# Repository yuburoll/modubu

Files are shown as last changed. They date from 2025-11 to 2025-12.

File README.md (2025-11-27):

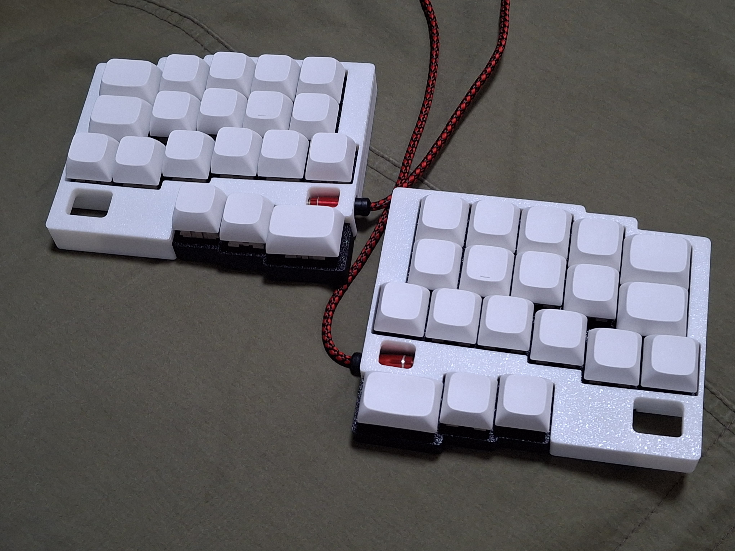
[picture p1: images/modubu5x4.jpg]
modubuImage


# modubu

[한국어 설명은 이곳에서 보실 수 있습니다](README_ko.md)

semi-staggered(half row staggered, half column staggered) 38 key split keyboard under 100x100mm PCB

The name "modubu" is tofu square in Korean.

Started idea on my old sketch and [KeeNoard](https://github.com/yuburoll/KeeNoard), finished and polished the idea thanks to the great [DYA Dash](https://cormoran.github.io/dya-dash-keyboard/).

(Really surprisingly, I made this similar layout when I don't know about DYA Dash.)

credit for 우주신제품(wujusinjepum), the anonymous who named this keyboard.

## Preparation

- 2x rp2040 zero (boards formly created by waveshare) (Approx. 4-8$)

- 2x modubu PCB Boards (5 boards are 2$ on JLC w/o shipping cost)

- 1x printed case sets, 6 parts total (Approx. 12$ if you buy printed one on JLC)

- 38x diodes (Approx. 1$)

- 22x M2x6 screws, flathead (Approx. 1$)

- 2x PJ320A 1/8(3.5mm) TRRS connector (Approx. 1$)

- 1x 1/8(3.5mm) TRRS cable (Approx. 2$, may TRS cable can take the place.)

- 38x MX Hotswap Sockets (Approx. 4$) (or, use soldering version)

- 38x MX Keyswitches & Keycaps (Maybe this cost varies too much. 10$ on average)

Approx. 37-41$(w/o shipping cost) needed to build one.

## Default Keymap

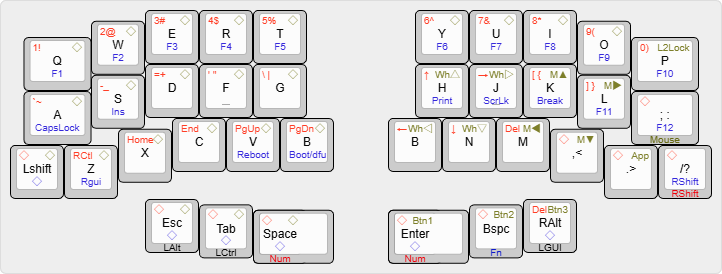
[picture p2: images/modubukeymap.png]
keymapImage


Holding the key triggers front legend.

There is three layers - Num, Mouse, Fn - which can be noticed by the color legends. ◇ Means Transparent; which uses base keymap.

## Build Guides

work in progress. sorry!

You can see the images in the folder, which uploaded for build guides. Especially you may see how to solder the controller board, because this uses surface mounting by castelated pins.

This uses [qmk](https://qmk.fm/) to build the firmware. Copy "modubu" folder which is in "firmware/qmk" directory to "qmk_firmware\keyboards" folder, and build it via qmk msys.

Or, simply flash uf2 in "uf2Examples" folder by changing rp2040 zero in dfu mode, which can be executed by holding boot button while plugging in usb c. Vial versions are also prepared.

## Notes

(from my reddit reply) 

I made this keyboard for very local and ethnic layouts - Especially Koreans.

Koreans have lots of vowels, so we use left hand for consonants and right hand for vowels. The tragedy starts from here: B position is vowel(ㅠ, yu) in Korean keyboard, so very lots of Korean typers press B in right hand, still they use B in left hand when they typing English words.

Many Korean split ergo keyboard users literally suffers with B position problem; and this is one of most stiff learning curve of them. Some exchanges semicolon to B key, some slides the bottom row or have double B (zxcvbnm,./ => /zxcvbnm,. or zxcvbbnm,.) and some just get used to it.

And after the B, Koreans type many word like CamelCaseVariables (eg. past sentence "있었습니다(it-sut-SOUP-nee-da)" types like "dlTdjTtmqslek") - which make home row mods very cumbersome. We may have seperated shift key for this.

So that's why I made row stagger split design with additional keys: But I was surprised that I'm not the first one with this idea and layout.

## Licenses

all codes follow MIT license.

all designs and the hardware board follow CC BY-SA 4.0 license.

If you want to make a commercial product, it would be appreciated if you sponsor some bucks for me.

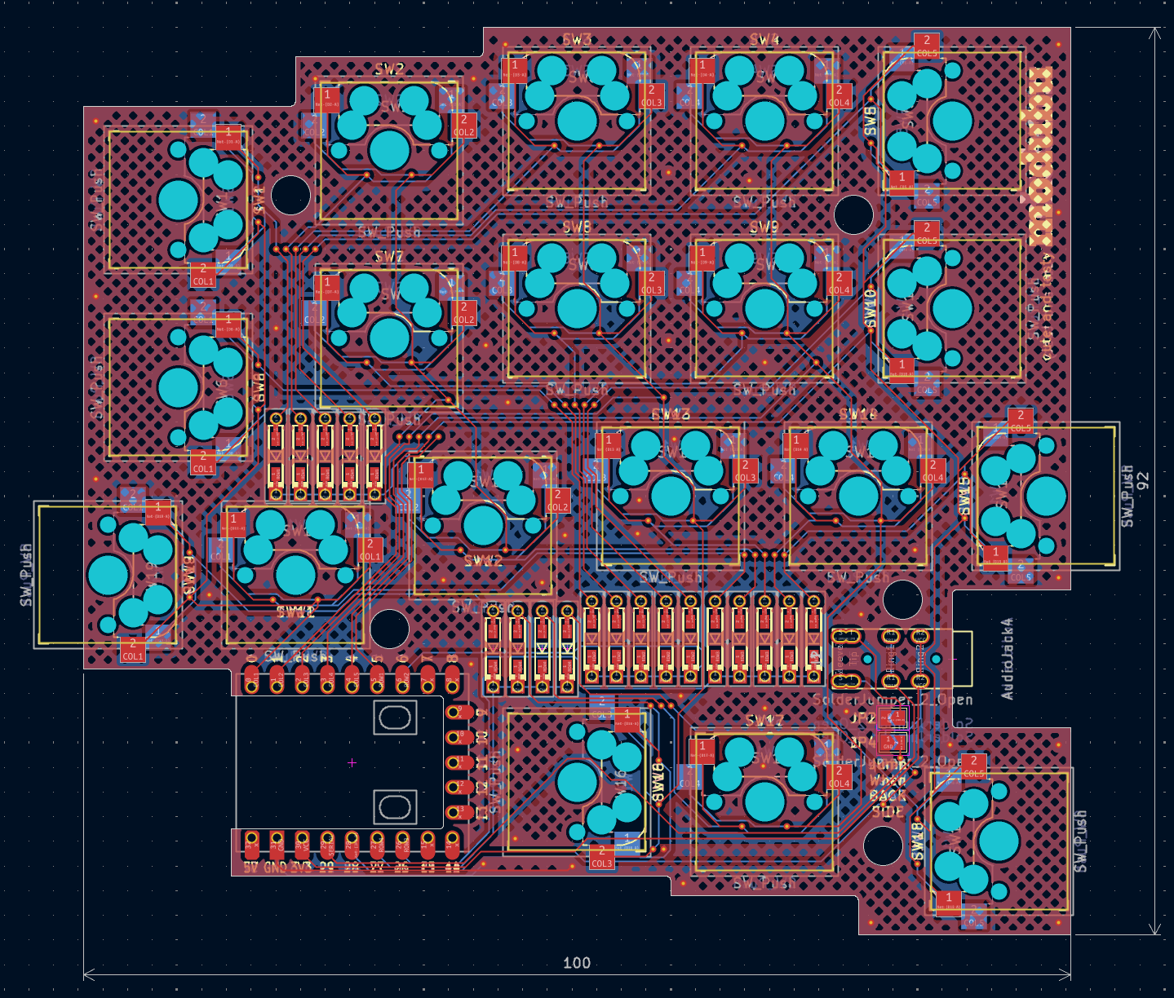
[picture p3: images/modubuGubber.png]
modubuGubber


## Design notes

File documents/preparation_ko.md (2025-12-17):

# 준비물과 구매처

알리익스프레스 링크와 한국에서 구할 수 있는 곳의 링크를 올립니다. 국내에서 구하는 게 더 나은 경우 알리 링크를 굳이 올리진 않습니다.

(2025년 11월 26일 기준입니다. 작동하지 않는 링크가 있을 수도 있습니다.)

다른 좋은 스토어나 다른 좋은 구매처가 있다면 그 쪽을 이용해주세요. 구매 링크는 예시일 뿐이며, 일절 저에게 수익이 들어오지 않습니다...

필요한 파일은 [릴리즈 페이지](https://github.com/yuburoll/modubu/releases/)에도 업로드해 두었습니다.

## 모두부 pcb 보드 2장

- JLCPCB에서 맡기면 2달러에 제조, 1.5달러에 배송합니다. https://jlcpcb.com/

- [거버 폴더](../gubber) 안의 [modubu-gubber.zip](../gubber/hotswap/modubu-gubber.zip)을 다운로드 받아 사이트에 올려주시면 됩니다.

## 3d 프린팅된 케이스, 총 6파츠

- JLC3dp에서 맡기면 약 2달러에 한 파츠씩 sls 레진으로 제조해 줍니다. 위의 pcb 보드와 같이 구매해주세요. https://jlc3dp.com/

- 아니면, 직접 fdm 3d 프린팅해서 만들거나 fdm 출력대행을 찾아서 프린팅해 저렴하게 구성해도 좋습니다.

- [케이스 폴더](../case/stl) 안의 [modubu-case.zip](../case/stl/modubu-case.zip)을 다운로드 받아 출력소에 전달해주시면 됩니다.

customization 하위 폴더 안에 메쉬 백플레이트도 제공하고 있습니다.(FDM으로 이걸 인쇄하는 경우, 인쇄 속도가 2배정도 차이가 나서 좀 더 비쌀 수도 있습니다.)

## rp2040 zero 보드 2개

- 알리: https://www.aliexpress.com/item/1005006865919374.html 
 
- 국내: https://smartstore.naver.com/plumkit/products/8734103090 핀헤더 미부착으로 구매해주세요.

https://www.nologo.tech/ 이 회사의 rp2040 supermini도 사용할 수 있을 것으로 생각됩니다.

## PJ320A 3.5mm TRRS 커넥터 2개

- 알리: https://ko.aliexpress.com/item/32951864590.html
 
- 국내: https://smartstore.naver.com/sagaklabs/products/9085223192

## MX 핫스왑 소켓 38개

- 알리: https://ko.aliexpress.com/item/1005007232040760.html
 
- 국내1: https://smartstore.naver.com/sagaklabs/products/9090497445

- 국내2: https://smartstore.naver.com/nana-inc/products/8240806382

- 국내3: https://smartstore.naver.com/around_life/products/10187682355

## 다이오드 38개

납땜이 익숙하지 않다면 THT 다이오드를 쓰시는 걸 추천합니다. 니퍼도 준비해 주세요.

- 국내(THT): https://smartstore.naver.com/ic11401/products/618129765
 
- 국내(SMD): https://smartstore.naver.com/sagaklabs/products/9090469658

## M2x6 접시머리 스크류 나사 22개
 
- 국내: https://smartstore.naver.com/riwootool/products/5561795590 옵션 선택에 주의해주세요

## MX용 키스위치 38개와 키캡 세트

- 평소에 좋아하시는 거 구하시면 됩니다. 104키 세트까지는 필요 없고, 1u 쉬프트와 1u 추가키가 포함된 텐키리스~60% 구성용 키캡 세트면 충분합니다.
 
- 1.25u 4개(스텝 스컬쳐 2 기준 R4에 많이 할당된 사이즈지만, R2나 R3을 구할 수 있으면 좋습니다), 1.5u 2개(R4면 좋습니다), 1u 32개(R2 8개, R3 8개, R4 16개의 구성)가 필요합니다.

## 눈물 범폰 8~12mm 4개

- 다이소에서 8~12mm짜리 유리 미끄럼 방지 패드나 충격 방지를 찾으면 저렴하게 쓸만한 물건을 구할 수 있습니다.

## 3.5mm TRRS 케이블 1개 (TRS도 됩니다)

- 아무 케이블이든 좋고, 국내에서 쉽게 구하실 수 있을 겁니다.

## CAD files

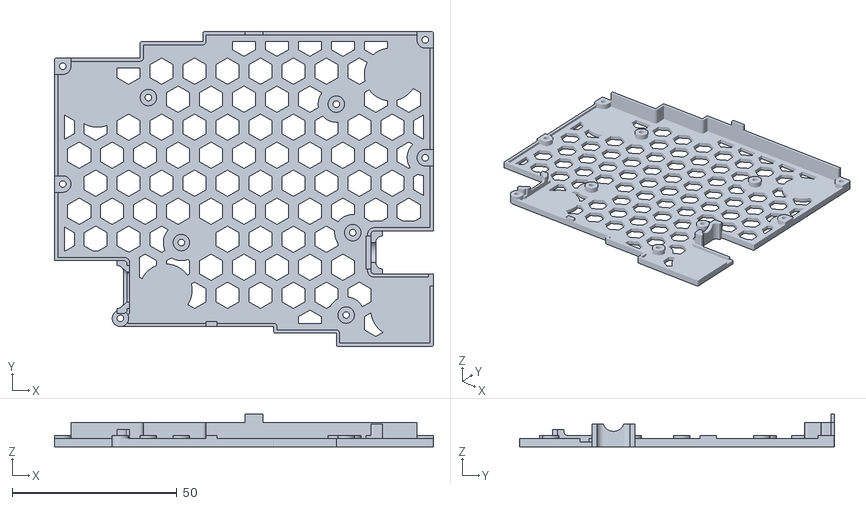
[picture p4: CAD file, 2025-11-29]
case/stl/intergratedCase/customization/modubuCase_Ldown_HexMesh.stl
115.0 x 95.5 x 10.0

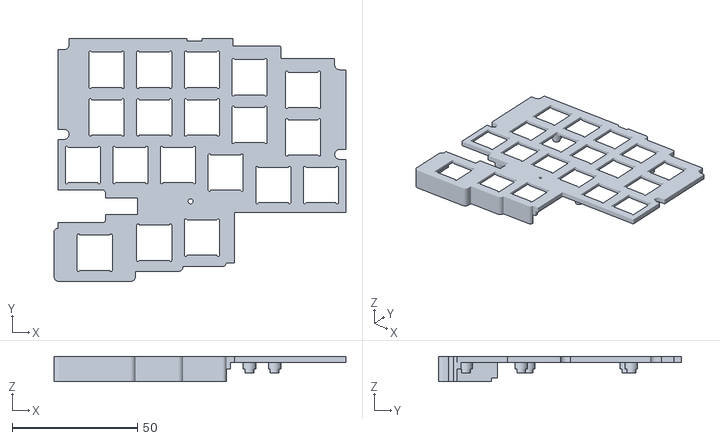
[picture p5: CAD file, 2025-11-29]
case/stl/intergratedCase/modubuCase_RMid.stl
116.5 x 97.0 x 10.0

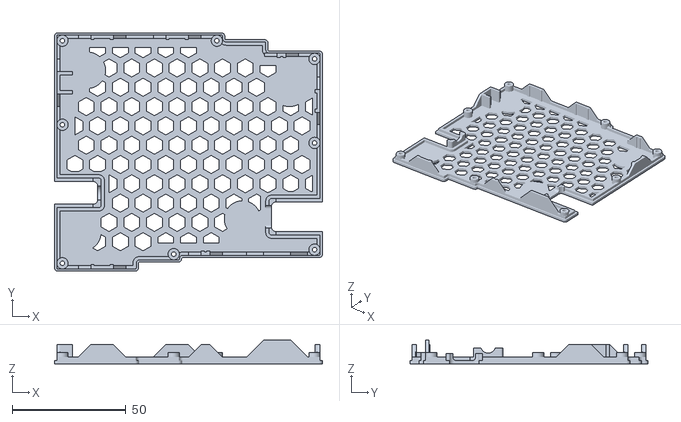
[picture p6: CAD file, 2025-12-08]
case/stl/leafspringCase/customization/modubuLeafspring_Rback_HexMesh.stl
118.0 x 105.0 x 10.5

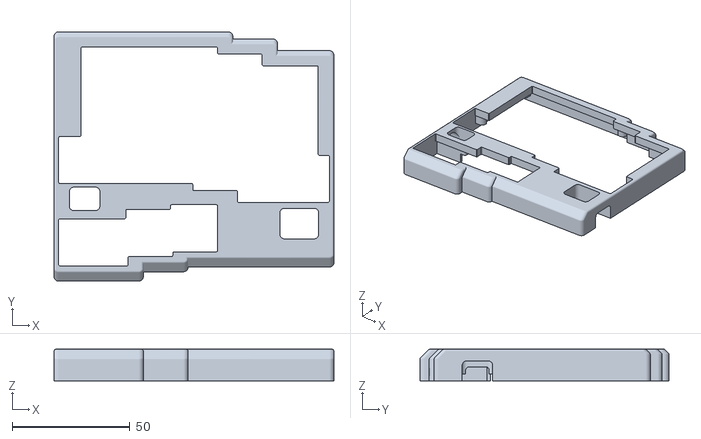
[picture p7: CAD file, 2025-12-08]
case/stl/leafspringCase/modubuLeafspring_Rtop.stl
119.0 x 106.0 x 13.5

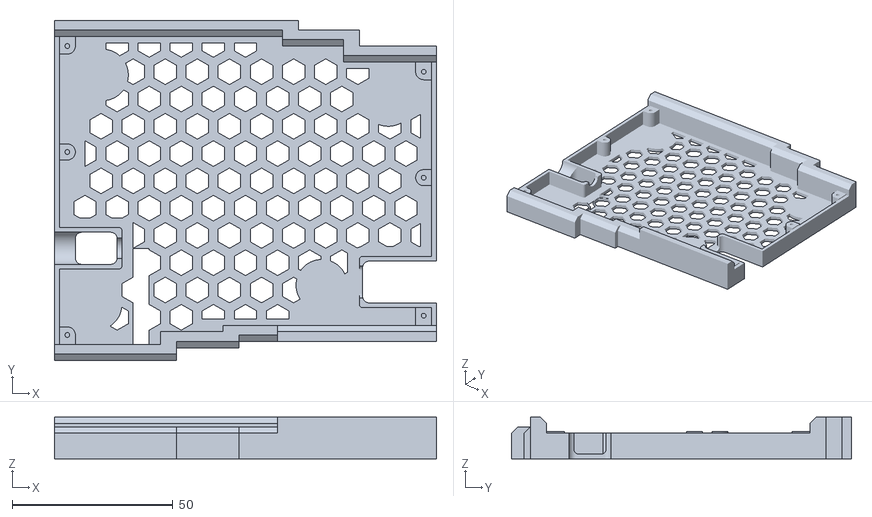
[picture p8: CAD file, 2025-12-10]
case/stl/vikiCase/customization/modubuViki_Rcase_HexMesh.stl
119.0 x 106.0 x 13.0

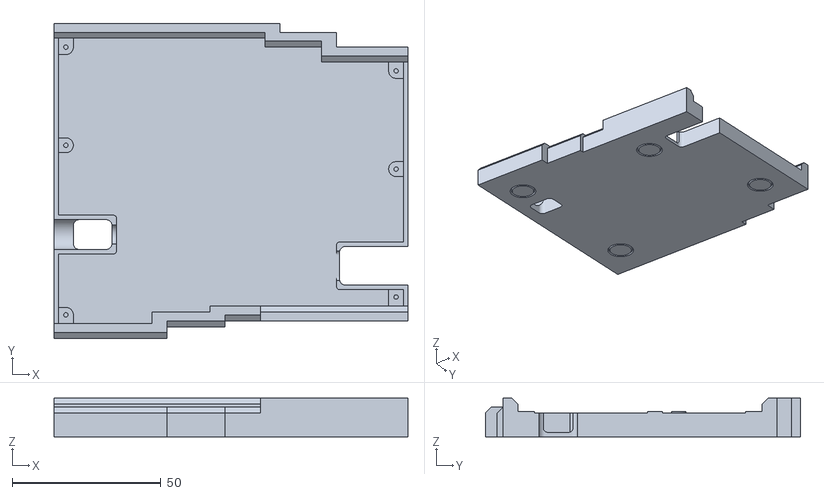
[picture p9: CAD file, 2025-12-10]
case/stl/vikiCase/modubuViki_RCase.stl
119.0 x 106.0 x 13.0

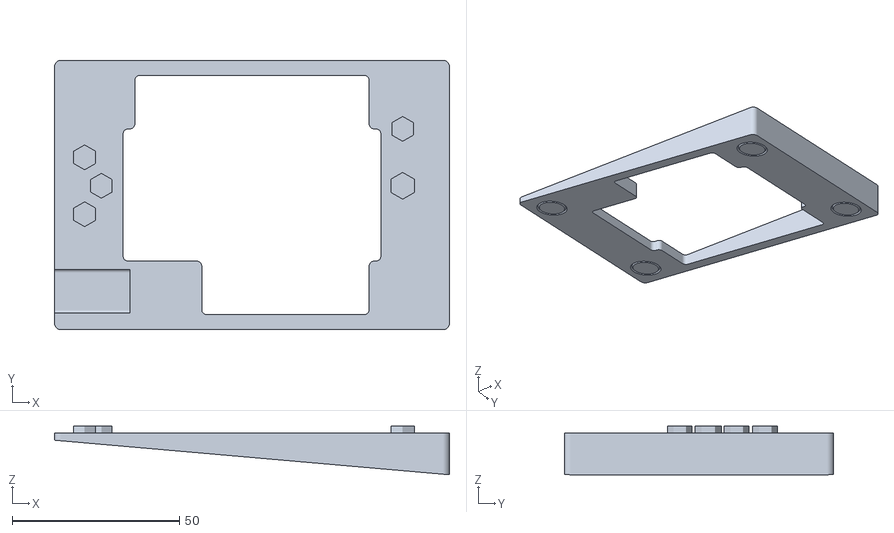
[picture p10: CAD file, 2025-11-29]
case/stl/intergratedCase/customization/modubuCase_LHexMeshTent.stl
118.0 x 80.5 x 14.5

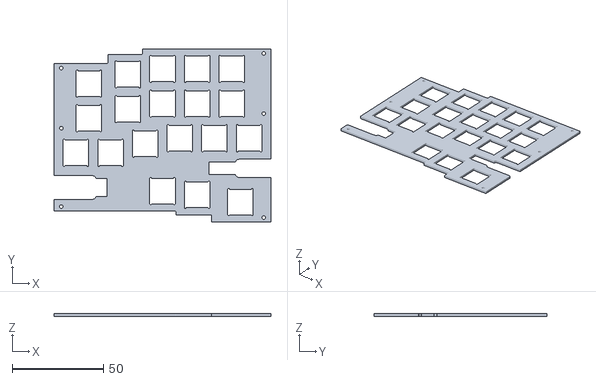
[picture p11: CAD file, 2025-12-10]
case/stl/vikiCase/modubuViki_Lplate.stl
119.0 x 95.0 x 1.50

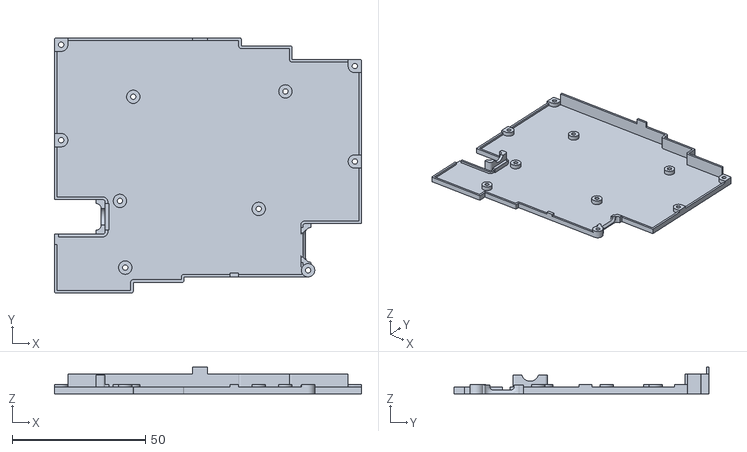
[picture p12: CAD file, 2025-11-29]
case/stl/intergratedCase/modubuCase_Rdown.stl
115.0 x 95.5 x 10.0

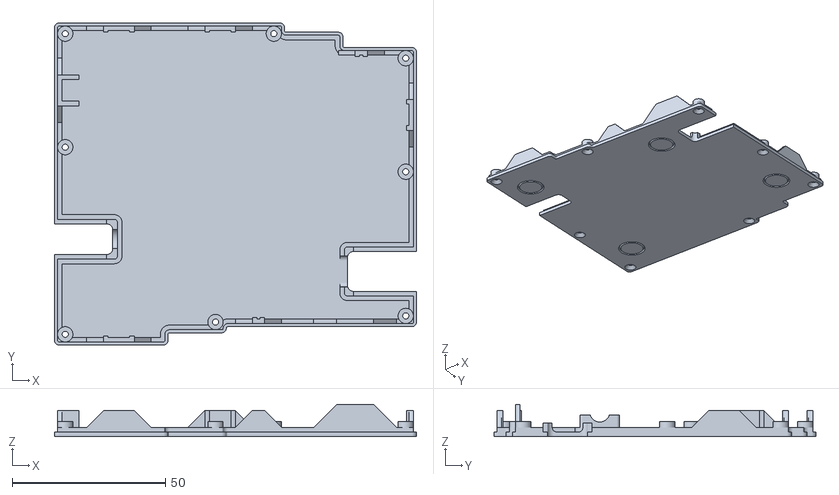
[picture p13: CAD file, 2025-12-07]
case/stl/leafspringCase/modubuLeafspring_Rback.stl
118.0 x 105.0 x 10.5

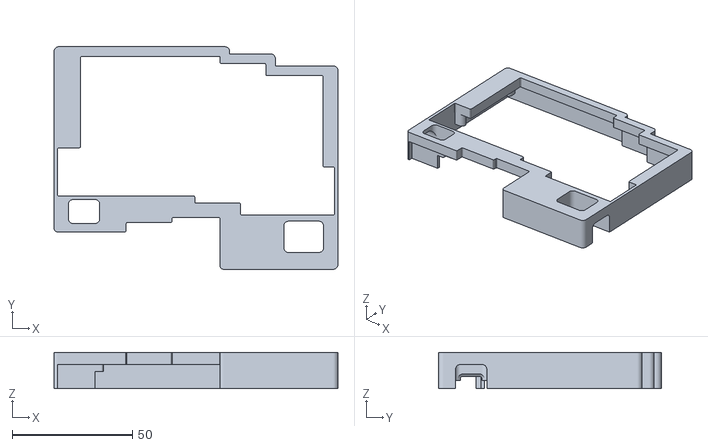
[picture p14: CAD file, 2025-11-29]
case/stl/intergratedCase/modubuCase_RUp.stl
118.0 x 92.5 x 15.0

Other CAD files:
case/stl/intergratedCase/modubuCase_LMid.stl
case/stl/leafspringCase/customization/modubuLeafspring_Lback_HexMesh.stl
case/stl/leafspringCase/modubuLeafspring_Ltop.stl
case/stl/vikiCase/customization/modubuViki_Lcase_HexMesh.stl
case/stl/intergratedCase/customization/modubuCase_RHexMeshTent.stl
case/stl/vikiCase/modubuViki_LCase.stl
case/stl/intergratedCase/customization/modubuCase_Rdown_HexMesh.stl
case/raw/modubu.3dm
case/raw/modubuLeafspring.3dm
case/raw/modubuViki.3dm
case/stl/intergratedCase/modubuCase_LUp.stl
case/stl/intergratedCase/modubuCase_Ldown.stl
case/stl/leafspringCase/modubuLeafspring_Lback.stl
case/stl/leafspringCase/modubuLeafspring_Lplate.stl
case/stl/leafspringCase/modubuLeafspring_Rplate.stl
case/stl/vikiCase/modubuViki_Rplate.stl

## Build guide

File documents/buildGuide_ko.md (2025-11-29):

# 빌드 가이드

modubu의 빌드 가이드입니다.

### 추가 자료

[**준비물과 구매처 가이드**](preparation_ko.md)

[**납땜 팁**](solderingTip_ko.md)

## 다이오드 납땜하기

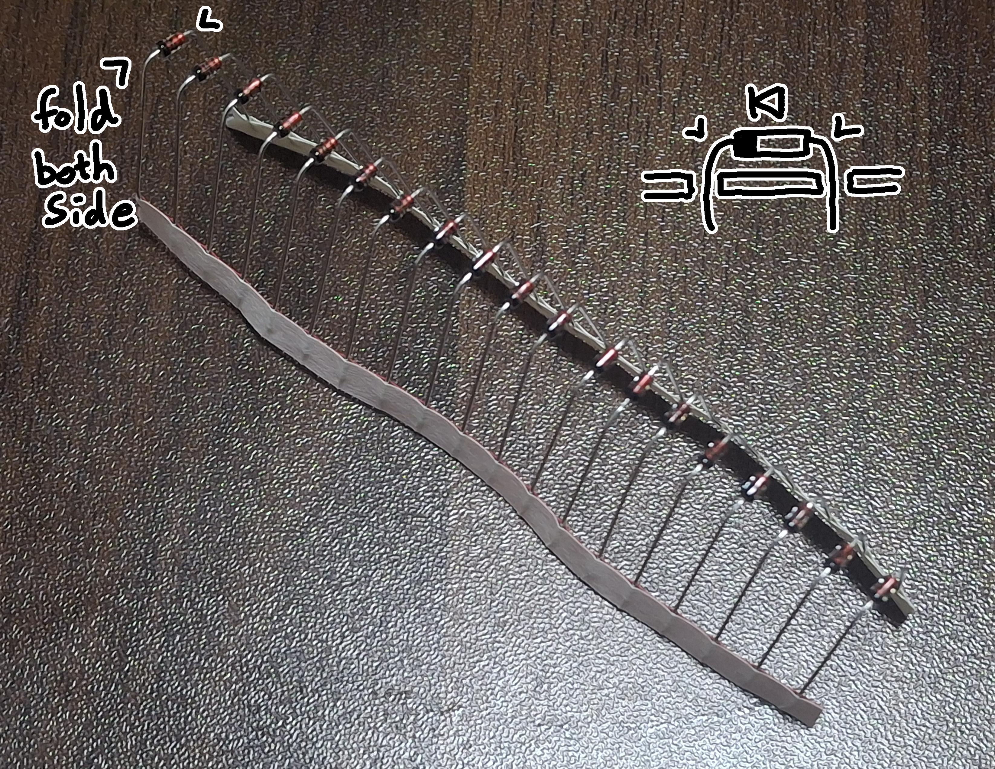
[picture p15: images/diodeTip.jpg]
diodeTip


THT 다이오드를 사용한다면, 다이오드의 다리를 ㄷ자로 미리 굽혀서 준비합니다.

다음의 두 이미지를 참고하면서 다이오드를 붙입니다. 앞면인지 뒷면인지는 상관없으며, **모든 다이오드 방향이 아래를 향해야 합니다.**

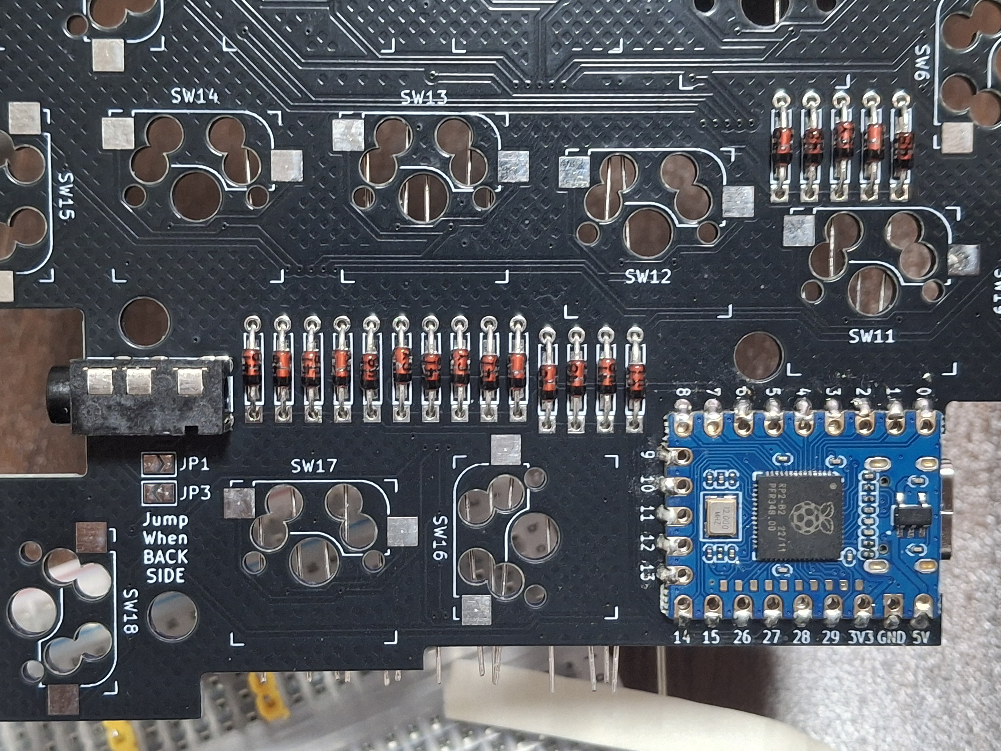
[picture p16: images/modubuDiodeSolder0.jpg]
DiodeSolder0


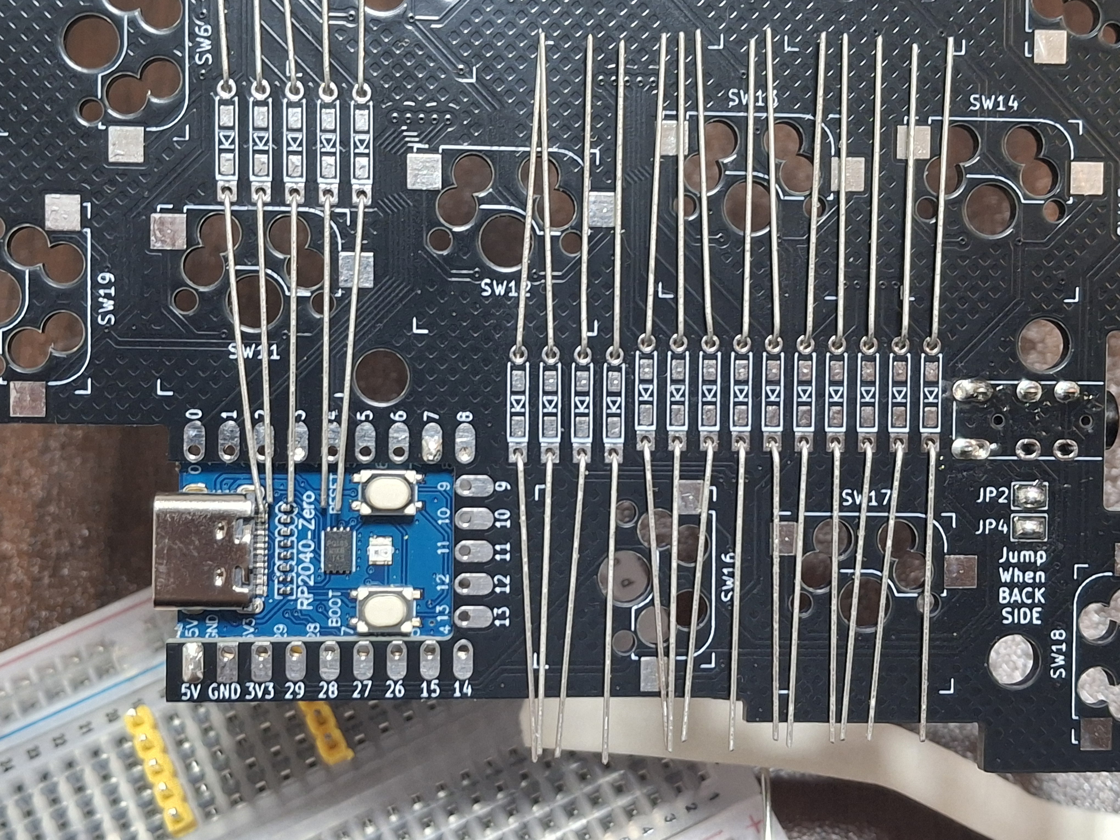
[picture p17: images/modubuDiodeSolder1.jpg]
DiodeSolder1


납땜을 마치면 다이오드의 뻗어난 잔가지 다리부분을 니퍼로 모두 자릅니다. 주변 패드에 닿지 않게 바짝 당겨서 잘라둡니다. 자를 땐 튕겨나가지 않도록 꼭 다리를 손가락으로 잡고 자릅시다.

SMD 다이오드를 사용할 땐 다이오드 위치의 한 쪽 패드에 납을 묻히고, 납을 묻힌 패드에 열을 가하면서 패드의 납이 녹았을 때 다이오드의 한 쪽 다리를 가져다 붙인 뒤, 반대쪽 다리를 땜합니다.

## 컨트롤러 보드 납땜하기

빵판이 있으면 편하기에 빵판을 쓰는 걸 기준으로 설명합니다.

빵판이 없다면, 다음의 과정을 참고하며 헤더 핀을 이용해 컨트롤러 보드를 pcb 위에 정렬한 뒤 땜해주세요.

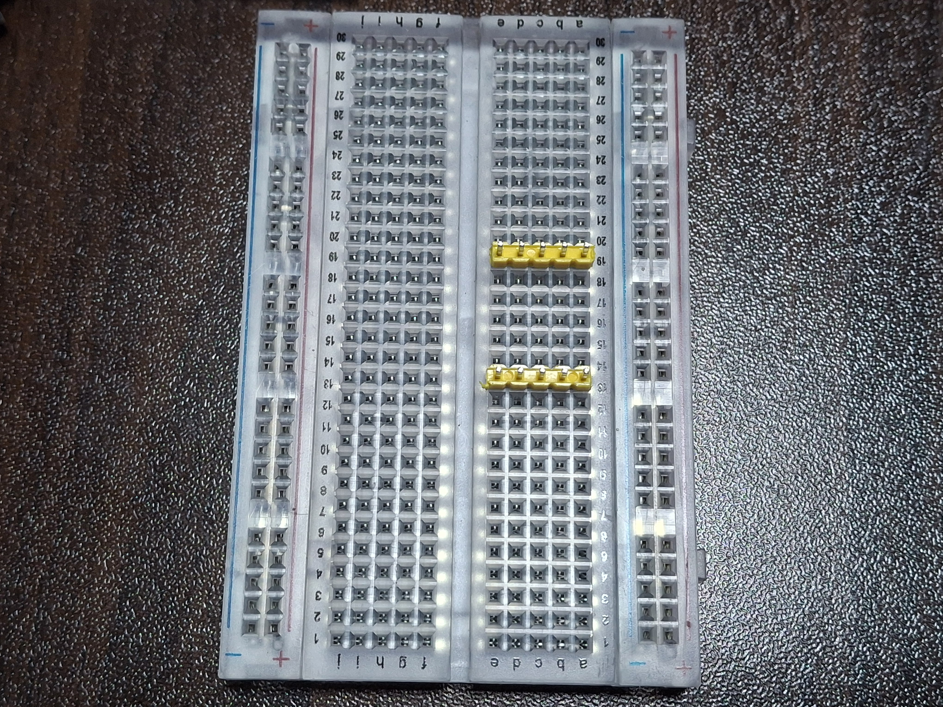
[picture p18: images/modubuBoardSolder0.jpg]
BoardSolder0


컨트롤러 보드의 양옆 간격만큼 벌려둔 상태로 빵판에 위치 정렬을 위한 핀을 꼽아둡니다. 동봉되어있을 헤더 핀들 중 짧은 쪽을 사용합니다.

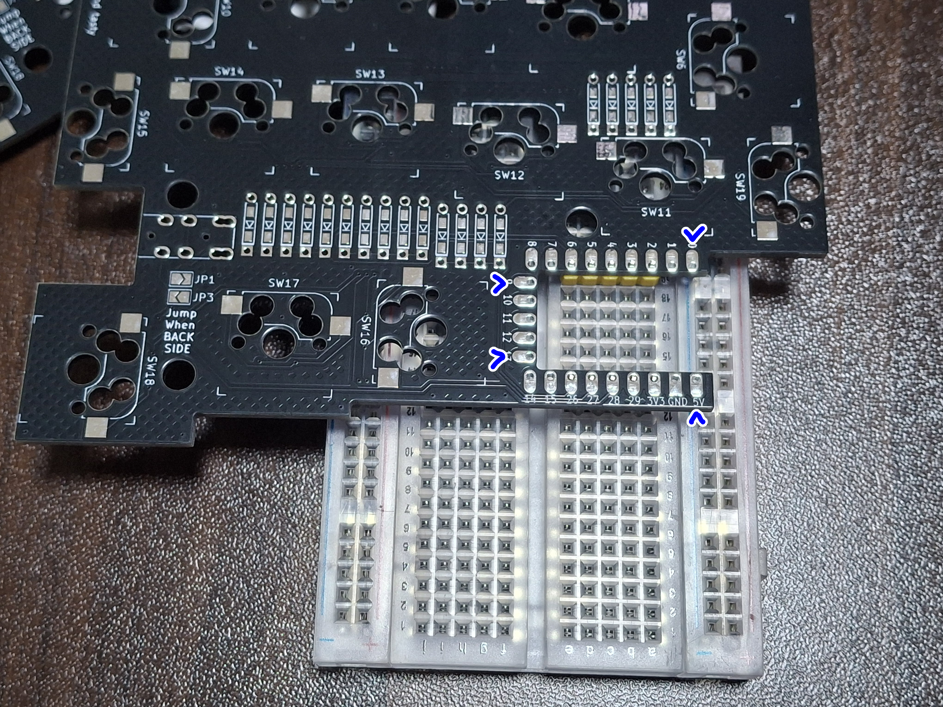
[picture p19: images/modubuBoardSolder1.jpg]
BoardSolder1


이 위에, 사진처럼 **보드의 오른쪽용 면을 위로 한 채로 pcb를 얹습니다.** **0번 핀, 5v 핀, 9번 핀, 13번 핀에 위치 정렬용 핀이 꼽히지 않도록 합니다.** 

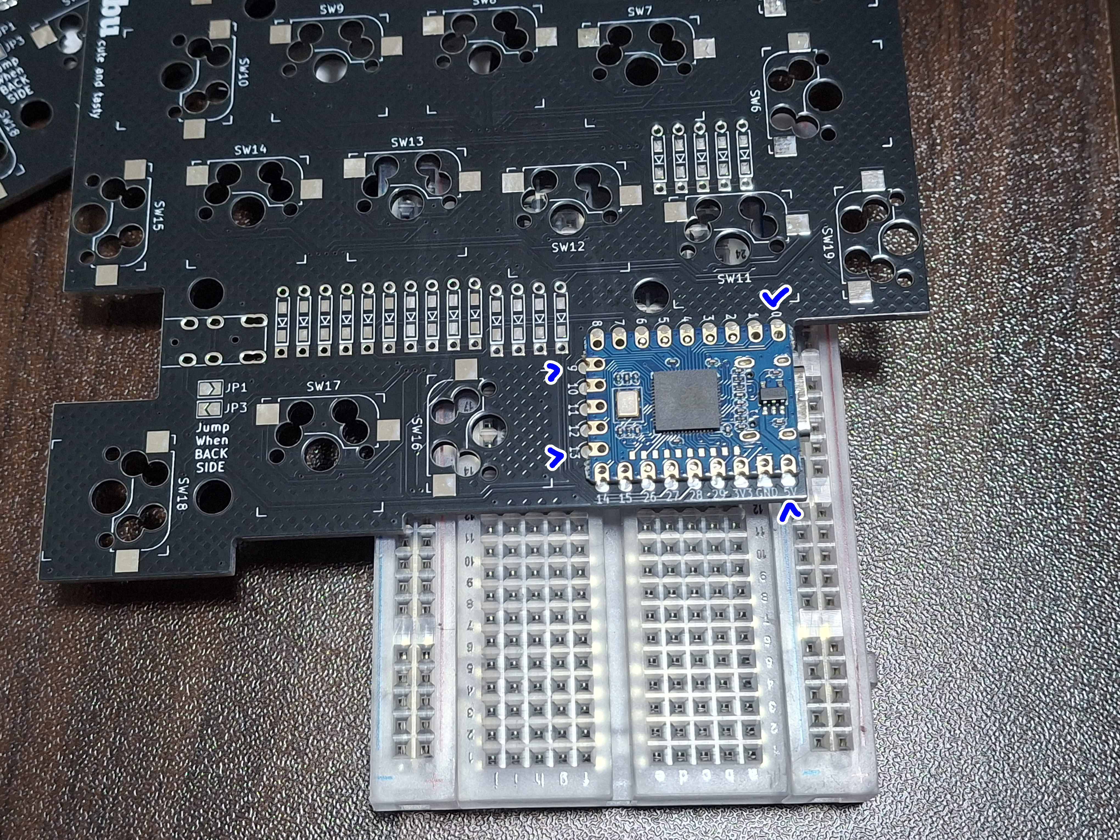
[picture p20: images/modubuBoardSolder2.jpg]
BoardSolder2


이 위에, 사진처럼 프로세서 면이 위로 가도록 컨트롤러 보드를 얹습니다. 위치 정렬을 확인하고, pcb 위에 적힌 글을 참고해 핀들이 제대로 위치되어있는지 확인합니다.

**0번 핀, 5v 핀, 9번 핀, 13번 핀을 먼저 땜하고 위치 정렬용 핀을 뗍니다.** 캐슬레이티드 핀, 즉 울퉁불퉁한 핀 테두리와 pcb의 패드를 납땜해 연결합니다.

이후 나머지 프로세서 핀 부분을 땜합니다.

**키보드 두 쪽 모두 똑같은 면에 똑같은 방향으로 프로세서 보드를 붙여야 합니다.**

## 컨트롤러 보드에 펌웨어 올리기

컨트롤러 보드의 Boot 버튼을 누르며 usb를 연결하면 이동식 디스크가 하나 뜹니다. (이를 dfu모드라고 합니다.)

[uf2examples 폴더](../firmware/qmk/uf2examples) 안에 있는 .uf2 파일을 해당 이동식 디스크에 집어넣으면 펌웨어가 들어갑니다. vial 펌웨어를 올리시는 걸 추천드립니다.

펌웨어에는 [qmk](https://qmk.fm/)를 사용하고 있습니다. 펌웨어를 직접 만들고 싶다면 "firmware/qmk" 경로 내의 "modubu" 폴더를 "qmk_firmware\keyboards" 경로로 붙여넣어 qmk msys를 이용해 빌드하면 됩니다.

완전히 조립된 이후 펌웨어를 올리려면 한 쪽은 버튼을 누를 수 없어 문제가 생깁니다. 그래서 **컨트롤러 보드를 납땜한 직후 펌웨어를 올리시는 걸 추천합니다**.

펌웨어를 올린 이후 dfu 모드에 들어갈 땐 썸클러스터(엄지 버튼들)의 가장 안쪽을 누른 채 키보드를 연결하면 됩니다.

## 핫스왑 소켓 납땜하기

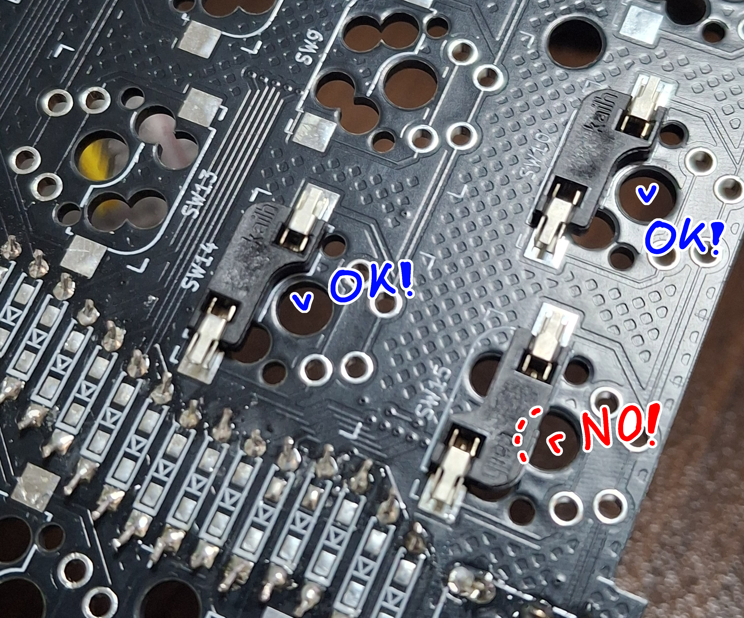
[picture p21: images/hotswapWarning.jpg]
hotswapWarning


(이미지의 보드는 [Boardloaf](https://github.com/yuburoll/Boardloaf)입니다.)

이제 각 손의 뒷면에 핫스왑 소켓을 납땜합니다. 핫스왑 소켓을 납땜할 땐 위 이미지처럼 역방향으로 꽂힐 수 있으므로, **pcb 보드에 있는 표시를 참고하며 정방향으로 꽂아서 땜합니다.**

## 커넥터 납땜하기 & 점프하기

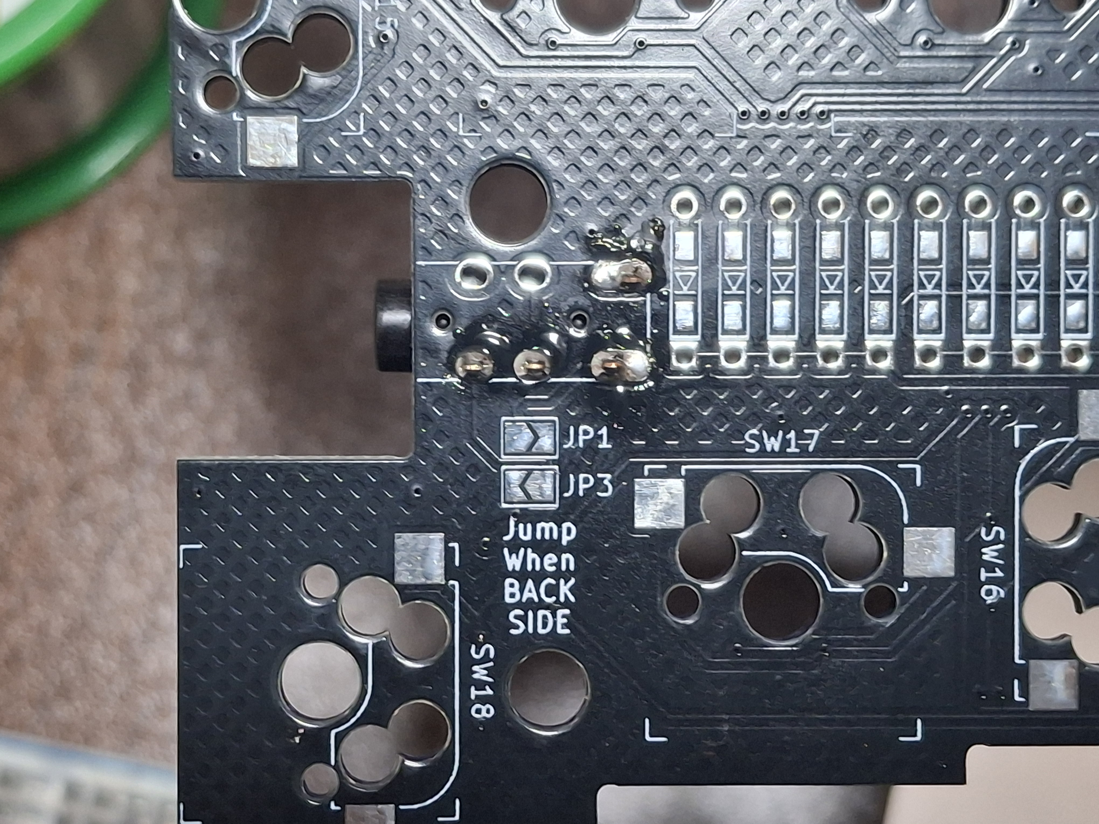
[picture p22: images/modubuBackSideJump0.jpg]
backsideJump0


각 손의 윗면 부분에 커넥터가 오도록 TRRS 커넥터를 배치하고, 뒷면에서 납땜합니다. 납땜할 때 마스킹 테이프 등으로 고정해두면 좋습니다.

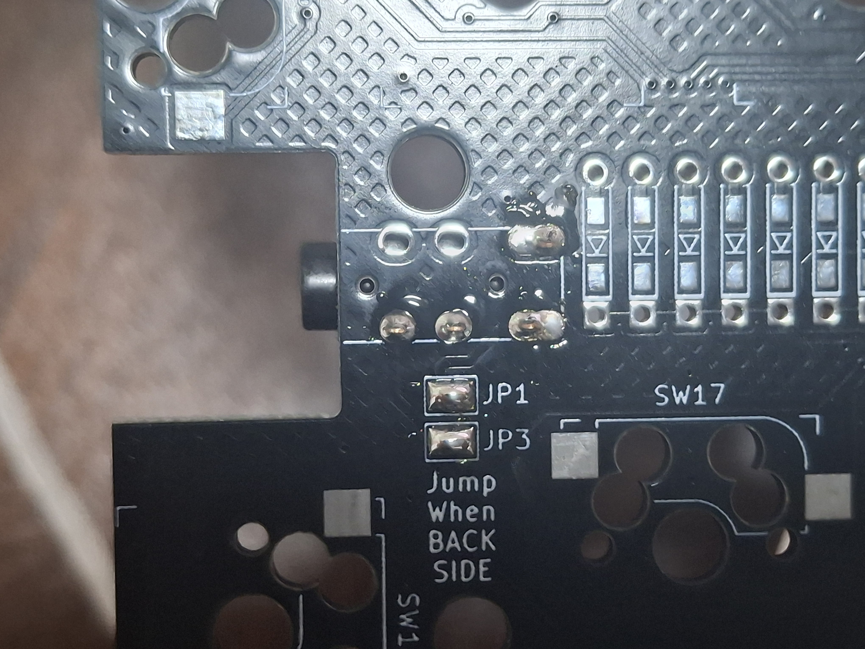
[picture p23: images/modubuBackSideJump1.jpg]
backsideJump1


이 면을 보고 있는 상태에서, "JUMP when BACK SIDE"라는 문구 위의 점퍼 두 점을 땜납으로 점프합니다. 반대쪽 면(=커넥터가 올라가 있는 윗면)은 하지 않습니다.

땜납의 두 부분을 인두기로 최대한 동시에 대고, 땜납을 물방울처럼 솟아오를 만큼 공급하면 서로 붙으면서 이어지는 느낌이 납니다. 이때 떼 주면 서로 붙습니다.

잘 안 되면 점퍼 부분을 잠시 식혔다가, 충분한 양의 플럭스를 팁과 점퍼에 묻히고 다시 시도해보세요.

## 조립상태 확인하기

다음 두 이미지를 참고해서 조립이 제대로 됐는지 확인합니다. 다이오드가 올라가 있는 면은 방향만 맞다면 상관 없습니다.

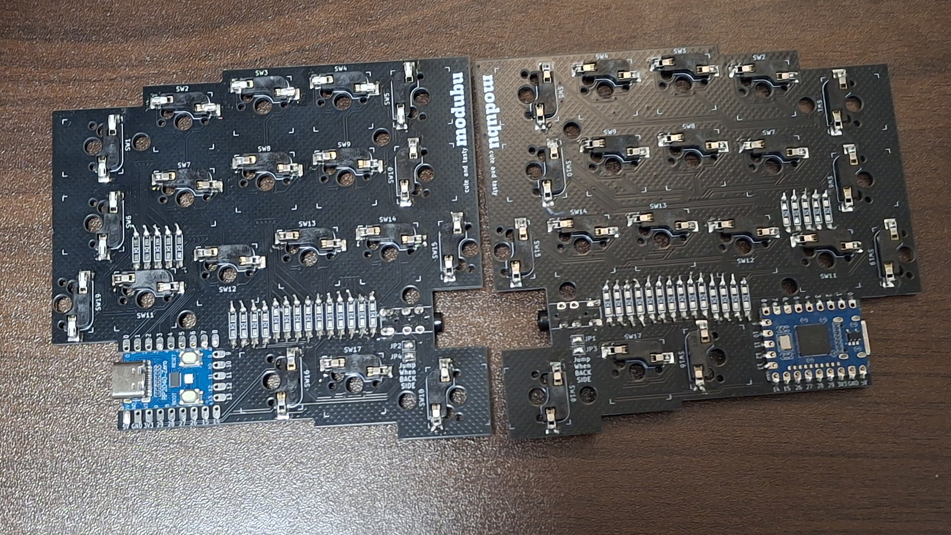
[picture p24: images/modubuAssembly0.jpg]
assembly0


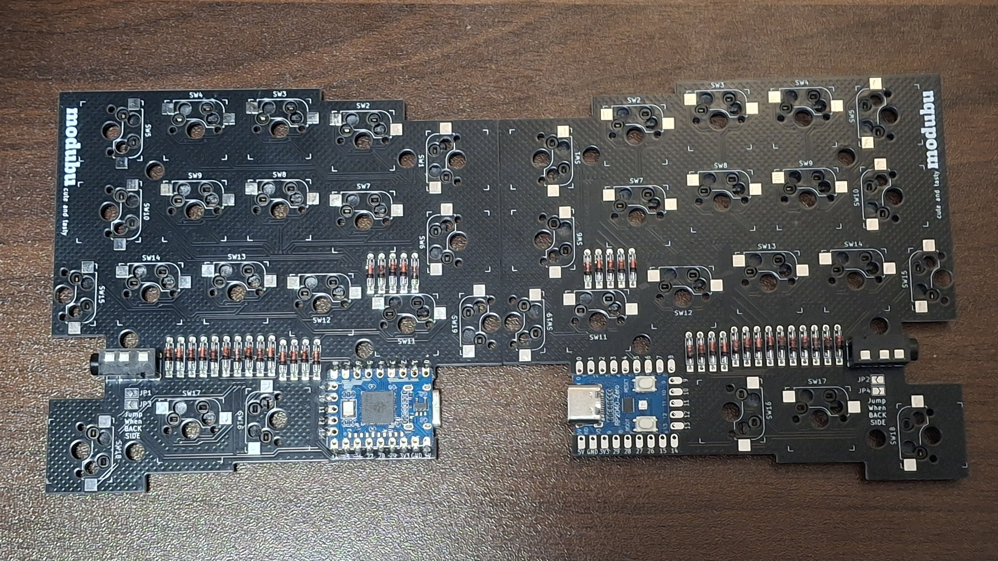
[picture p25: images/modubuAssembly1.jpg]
assembly1


## 케이스와 스위치 조립하기

다음 두 이미지를 참고해서, Up와 Mid로 표기된 케이스 부품과 스위치를 미리 조립합니다.

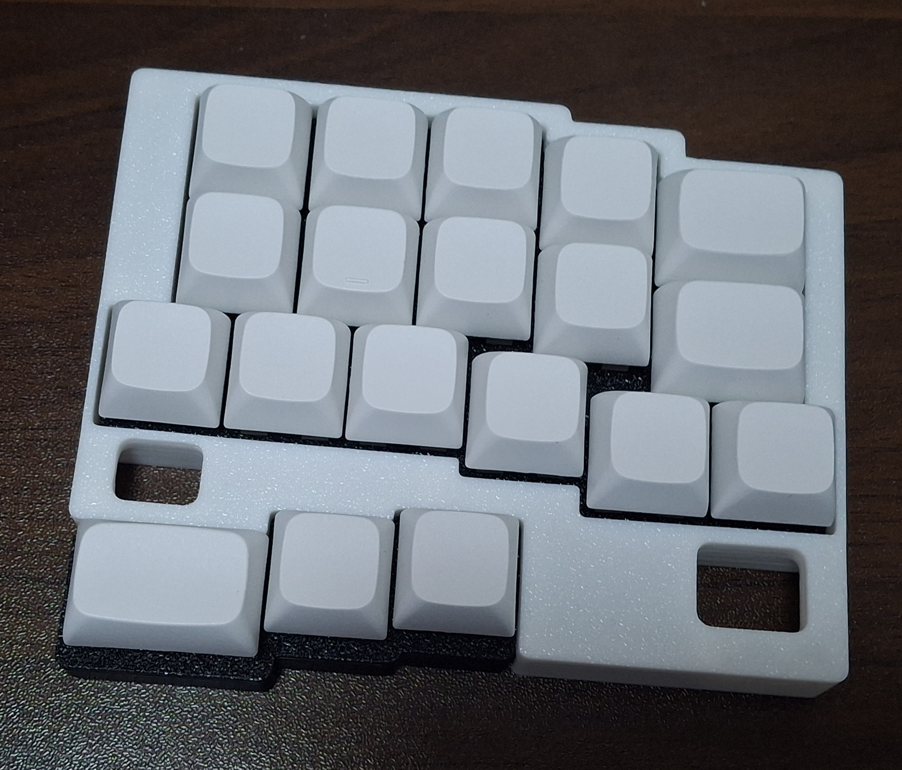
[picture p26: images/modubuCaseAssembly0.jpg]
caseAssembly0


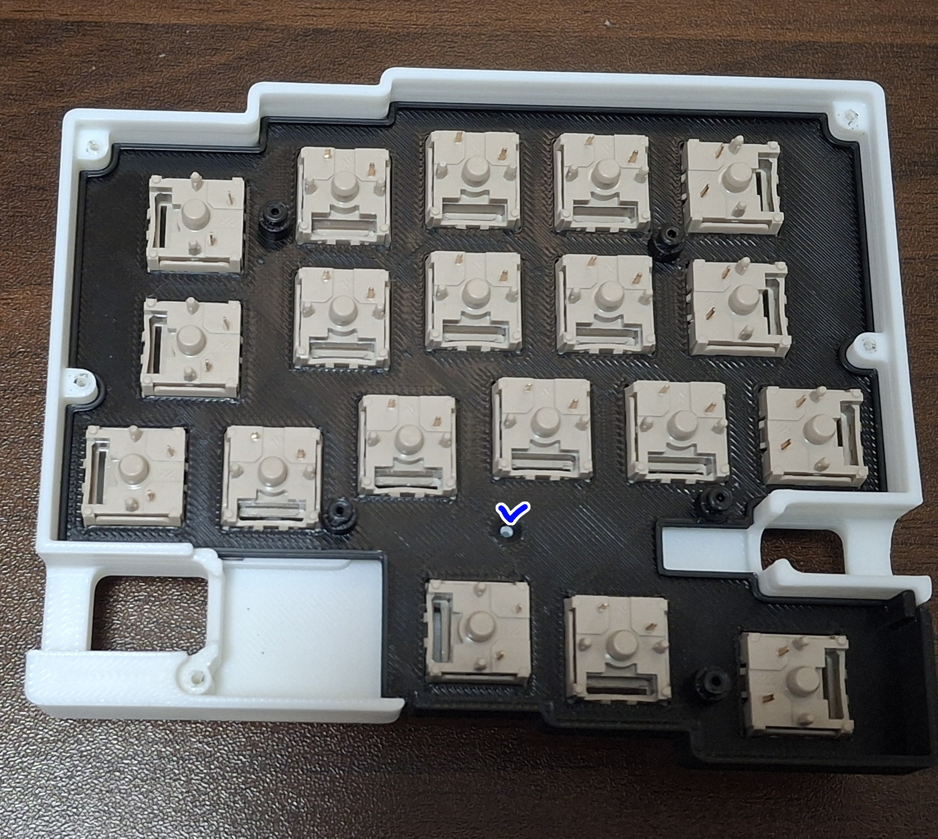
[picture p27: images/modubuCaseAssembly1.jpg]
caseAssembly1


조금 더 튼튼한 고정을 원한다면 위 이미지의 v자 마크가 붙은 부분에 나사를 끼웁니다.(필수는 아닙니다. 너무 세게 조이면 나사 끝이 케이스 바깥으로 살짝 튀어나오니 주의)

이 위에 다음 이미지처럼 조립한 보드를 얹습니다.

pcb 보드를 얹을 땐 바깥쪽의 스위치부터 먼저 보드에 눌러 핫스왑과 결합시킨 다음 나머지를 결합시키는 걸 추천합니다.

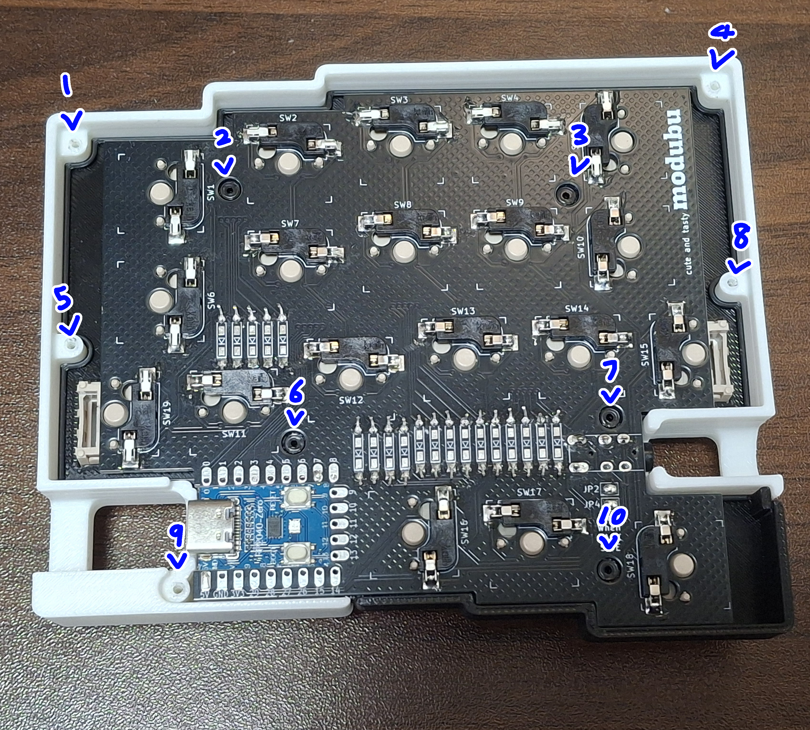
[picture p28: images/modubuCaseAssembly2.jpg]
caseAssembly2


모든 스위치가 핫스왑에 제대로 결합됐음을 확인하면 Down으로 표기된 케이스의 바닥 부분을 올려 덮고, v자 마크가 붙은 부분에 나사를 끼워 조립합니다. 한 쪽마다 총 10곳 입니다.

마지막으로 키보드의 범폰 위치에 범폰 4조각을 붙이면 완성입니다.

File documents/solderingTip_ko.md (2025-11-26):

# 납땜 팁

납땜 관련 훈수들을 모아두었습니다.

## 준비물

- 납땜 인두기 & 받침대: 끝자락이 일자드라이버(chisel)처럼 되어있는 물건이 쓰기 편합니다. 적어도 온도를 섭씨 400~500도로 유지할 수 있는 물건을 사는 걸 추천드립니다.

- 땜납: 유연납과 무연납 중 골라서 쓰시면 됩니다. 유연납이 스트레스는 덜하지만, 아무래도 몸에 안 좋습니다.

- 솔더링 페이스트(플럭스): **납땜의 신**입니다. 납땜이 잘 안 된다 싶으면 구두약 플럭스로 인두 끝을 훑어 자주 닦아주시기 바랍니다. 

- 물에 적신 스폰지/키친타올, 혹은 인두팁 클리너(구리 솜): 인두 팁에 남은 납 닦는 데 씁니다.

- 솔더 윅 혹은 납 흡입기: 잘못 납땜된 부분을 수정하는 데 씁니다. 초보라면 솔더 윅을 추천합니다.

- 니퍼: THT 다이오드의 다리를 납땜한 후 잘라내는 데 씁니다.

## 환기를 하자

땜납이 녹는 금속 흄도 문제지만 의외로 미량입니다. 땜납 속의 송진 플럭스가 녹고 타는 연기가 꽤 안 좋으며, 많이 생깁니다. 건강에 매우 안 좋으니 환기를 하거나, 환기를 할 수 없다면 공기 청정기를 필참하시기 바랍니다. 마스크는 꼭 쓰세요.

## 부품 납땜하기 전 확인을 여러 번 하자

납땜을 수정하는 거보다 잘못 납땜하지 않도록 예방하는 게 더 쉽습니다. 납땜을 수정할 땐 솔더윅에 플럭스를 묻히고 인두기와 같이 대거나, 플럭스를 살짝 묻힌 인두기로 납을 녹이는 동시에 납 흡입기를 밀착시켜 흡수합니다.

## 납이 안 붙는 것 같으면 플럭스를 바르자

인두 팁에 플럭스를 녹여 적시거나, 아니면 펜형 플럭스 제품을 사용해 기판에 바르면 좋습니다.

## 땜을 시작할 땐 인두기를 제일 먼저 대고, 땜을 끝낼 땐 인두기를 제일 마지막에 빼자

인두기를 제일 먼저 대 기판과 부품을 먼저 가열한 후에 땜납을 녹여 붙입니다. 끝낼 땐 땜납 먼저 떼고 인두기를 마지막에 뗍니다.

## 부품을 임시로 고정할 땐 마스킹 테이프를 애용하자

소켓같은 부품은 땜하기 전 마스킹 테이프로 고정하면 좋습니다. 당연한 이야기지만, 뒤집어서 납땜하는 경우 부품을 고정하기 어렵기 때문입니다.

## 납땜을 마친 후에는 플럭스를 닦자

소독용 알코올을 묻힌 칫솔 등으로 남은 플럭스와 합선이 날법한 부분을 면밀히 닦습니다. 아예 알코올을 뿌려서 칫솔을 문지른 뒤 말려도 됩니다. 키보드 입력정도는 괜찮을 수 있으나, 인코더나 아날로그 입력이 들어가는 것들은 이런 플럭스 합선에도 취약한 모습을 보입니다.

## 문제가 생기면 다시 땜해보고 플럭스를 닦자

냉납이 나거나, 땜 양이 부족하거나, 오히려 많아서 옆을 침범한다거나, 플럭스를 타고 전기가 흘러 방해받는 경우에 문제가 생깁니다. 대부분은 납땜을 다시 하고 플럭스를 닦으면 해결됩니다.

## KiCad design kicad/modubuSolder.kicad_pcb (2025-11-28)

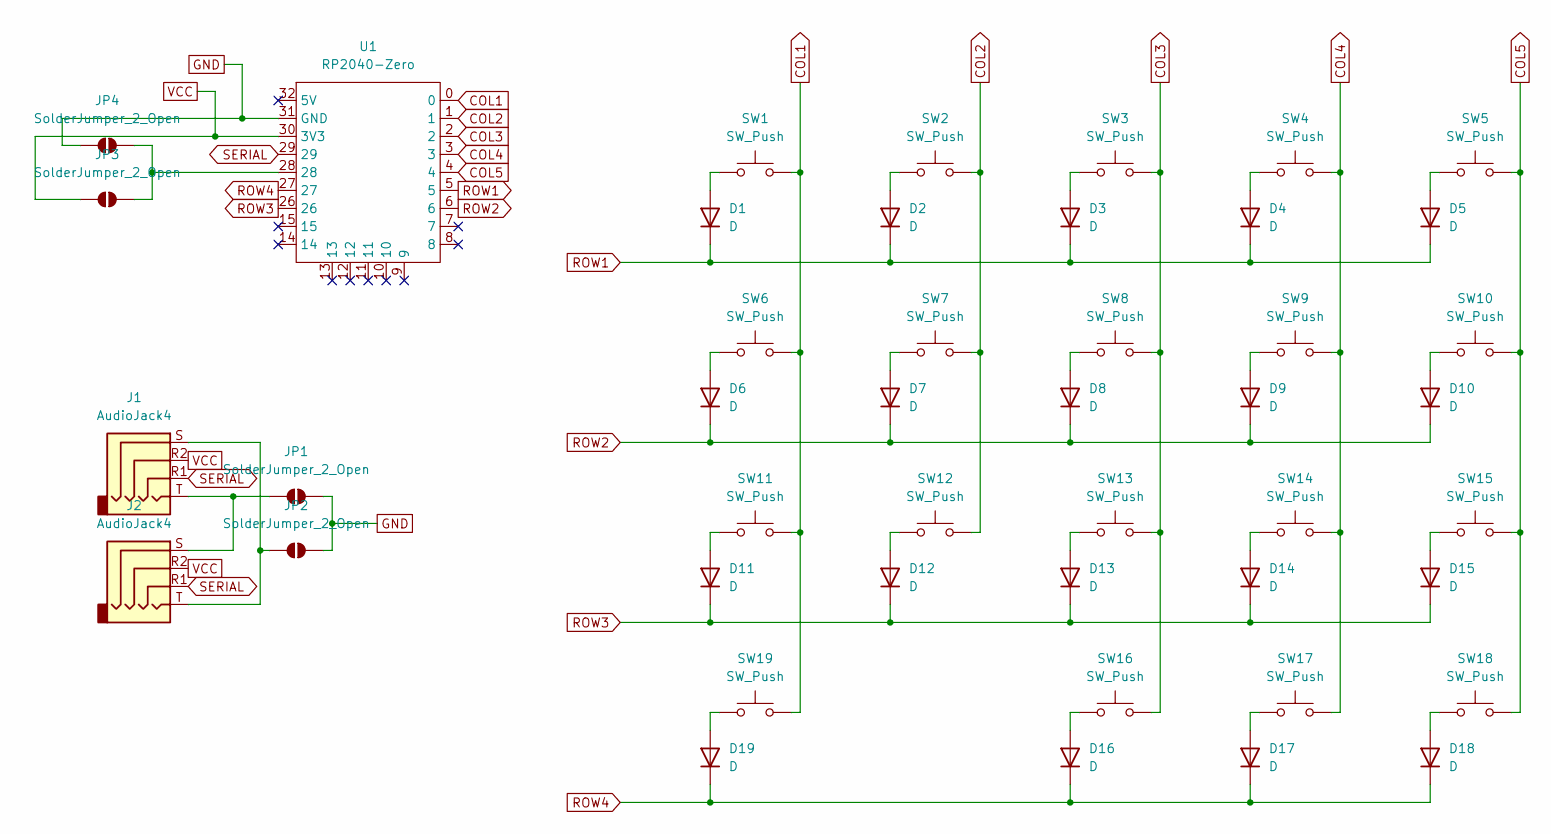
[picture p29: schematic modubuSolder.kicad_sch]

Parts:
D1, D2, D3, D4, D5, D6, D7, D8, D9, D10, D11, D12, D13, D14, D15, D16, D17, D18, D19: D
J1, J2: AudioJack4
JP1, JP2, JP3, JP4: SolderJumper_2_Open
SW1, SW2, SW3, SW4, SW5, SW6, SW7, SW8, SW9, SW10, SW11, SW12, SW13, SW14, SW15, SW16, SW17, SW18, SW19: SW_Push
U1: RP2040-Zero

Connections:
COL1: SW1.2, SW6.2, SW11.2, SW19.2, U1.0
COL2: SW2.2, SW7.2, SW12.2, U1.1
COL3: SW3.2, SW8.2, SW13.2, SW16.2, U1.2
COL4: SW4.2, SW9.2, SW14.2, SW17.2, U1.3
COL5: SW5.2, SW10.2, SW15.2, SW18.2, U1.4
GND: JP1.2 (B), JP2.2 (B), JP4.1 (A), U1.31 (GND)
unnamed: D1.2 (A), SW1.1
unnamed: D2.2 (A), SW2.1
unnamed: D3.2 (A), SW3.1
unnamed: D4.2 (A), SW4.1
unnamed: D5.2 (A), SW5.1
unnamed: D6.2 (A), SW6.1
unnamed: D7.2 (A), SW7.1
unnamed: D8.2 (A), SW8.1
unnamed: D9.2 (A), SW9.1
unnamed: D10.2 (A), SW10.1
unnamed: D11.2 (A), SW11.1
unnamed: D12.2 (A), SW12.1
unnamed: D13.2 (A), SW13.1
unnamed: D14.2 (A), SW14.1
unnamed: D15.2 (A), SW15.1
unnamed: D16.2 (A), SW16.1
unnamed: D17.2 (A), SW17.1
unnamed: D18.2 (A), SW18.1
unnamed: D19.2 (A), SW19.1
unnamed: J1.T, J2.S, JP1.1 (A)
unnamed: J1.S, J2.T, JP2.1 (A)
unnamed: JP3.2 (B), JP4.2 (B), U1.28
ROW1: D1.1 (K), D2.1 (K), D3.1 (K), D4.1 (K), D5.1 (K), U1.5
ROW2: D6.1 (K), D7.1 (K), D8.1 (K), D9.1 (K), D10.1 (K), U1.6
ROW3: D11.1 (K), D12.1 (K), D13.1 (K), D14.1 (K), D15.1 (K), U1.26
ROW4: D16.1 (K), D17.1 (K), D18.1 (K), D19.1 (K), U1.27
SERIAL: J1.R1, J2.R1, U1.29
VCC: J1.R2, J2.R2, JP3.1 (A), U1.30 (3V3)

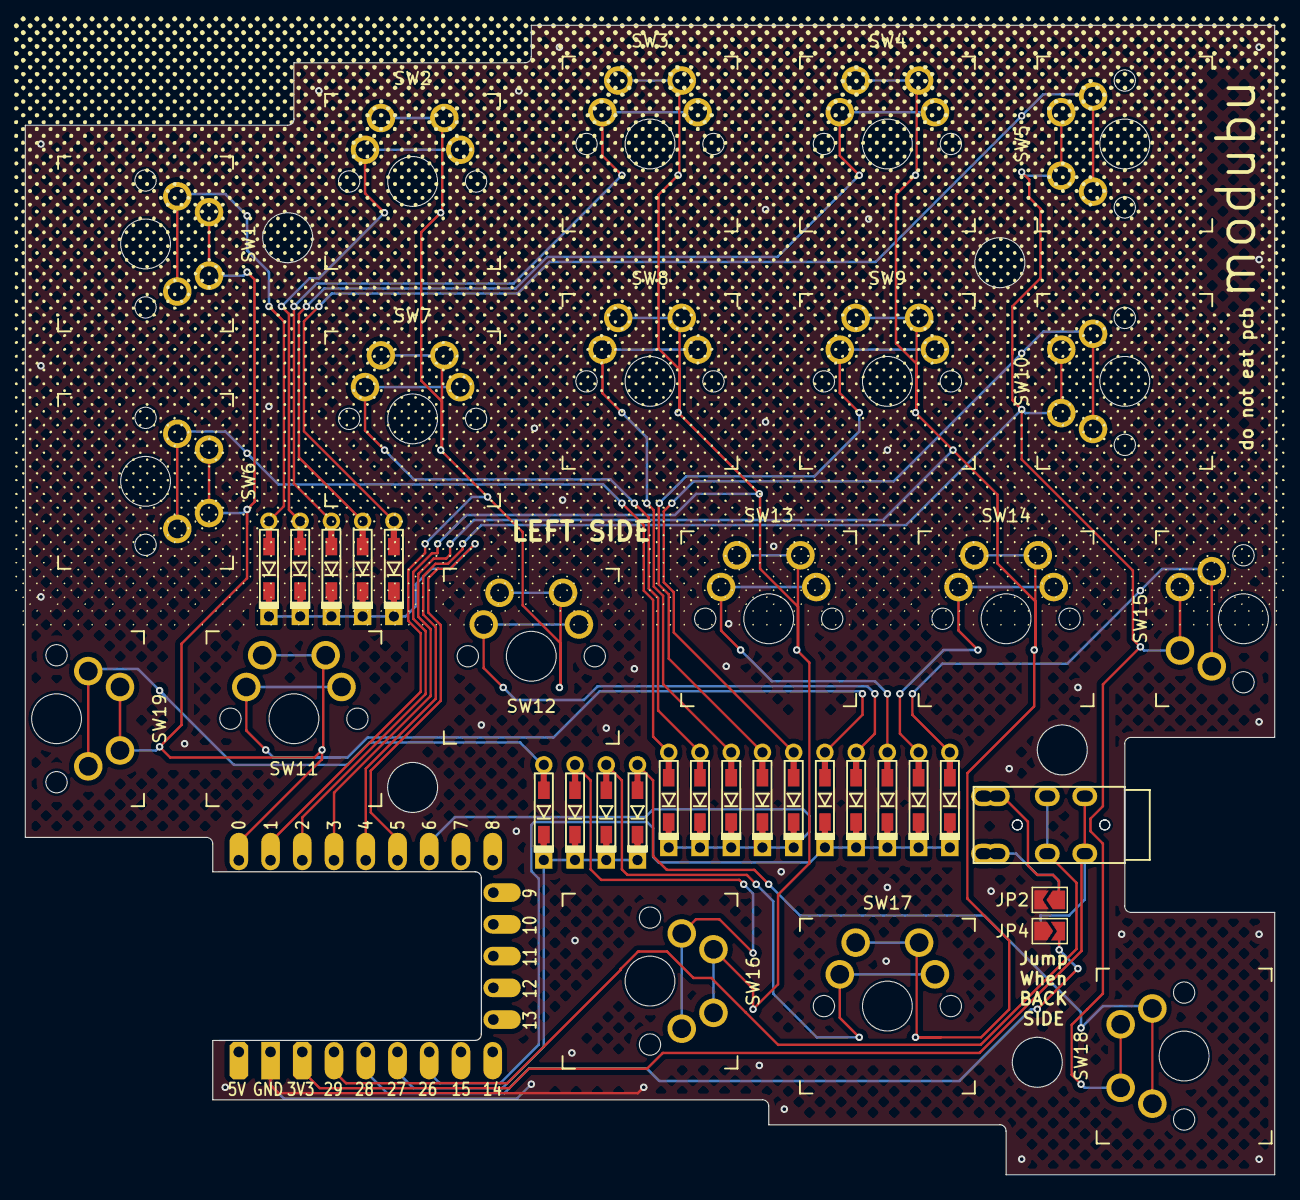
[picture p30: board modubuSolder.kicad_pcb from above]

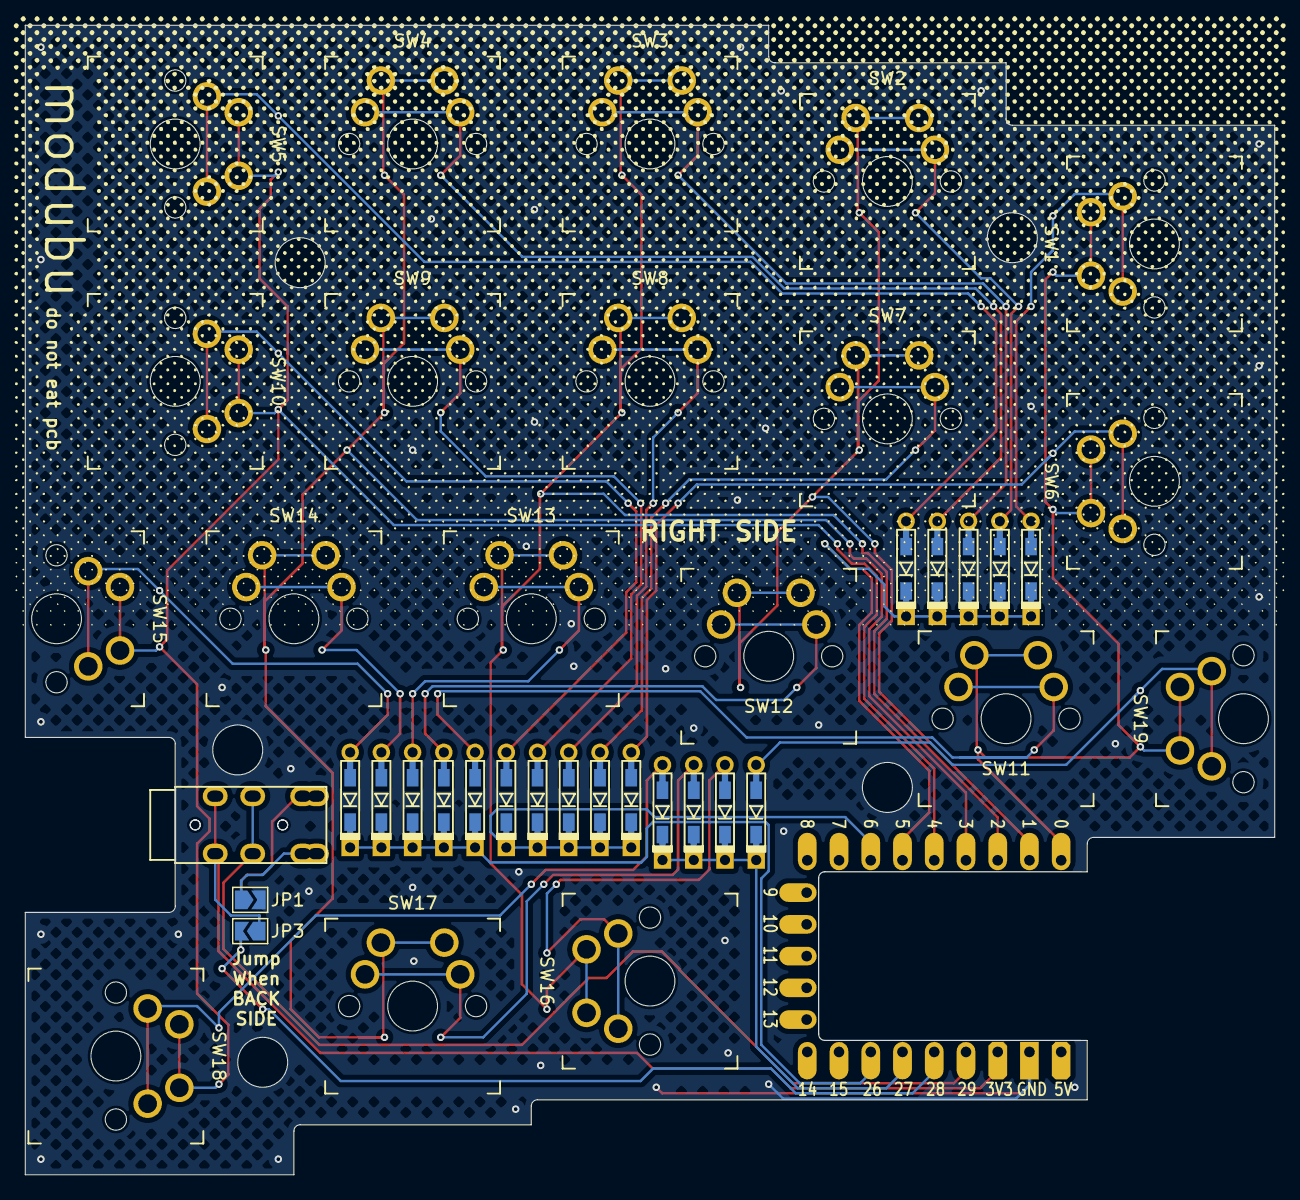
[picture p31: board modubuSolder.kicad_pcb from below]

Board: 2 copper layers, 100.0 x 92.0 mm, 45 parts (3 on the bottom side), 34 nets.

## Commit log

2025-11-14 first upload
    [modubu-B_Cu.gbr, modubu-B_Mask.gbr, modubu-B_Paste.gbr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]
2025-11-14 upload case design
2025-11-21 update case failure
2025-11-24 add bumpon place to case
    [modubu.3dm, modubuCase_Ldown.stl, modubuCase_Rdown.stl]
2025-11-25 add position silkscreen
    [modubu-B_Cu.gbr, modubu-B_Mask.gbr, modubu-B_Paste.gbr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]
2025-11-26 update case design
    [modubu.3dm, modubuCase_LUp.stl, modubuCase_Ldown.stl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]
2025-11-26 upload soldering board - sundubu
    [modubu-B_Cu.gbr, modubu-B_Mask.gbr, modubu-B_Paste.gbr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]
2025-11-27 edit gerber ground via
    [modubu-B_Cu.gbr, modubu-B_Mask.gbr, modubu-B_Paste.gbr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]
2025-11-27 add board art
    [modubu-B_Cu.gbr, modubu-B_Mask.gbr, modubu-B_Paste.gbr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]
2025-11-27 polish up board art
    [modubu-B_Cu.gbr, modubu-B_Mask.gbr, modubu-B_Paste.gbr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]
2025-11-28 update artwork
    [modubu-B_Cu.gbr, modubu-B_Mask.gbr, modubu-B_Paste.gbr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]
2025-11-28 update case for fdm minimal requirement
    [modubu.3dm, modubuCase_LMid.stl, modubuCase_Ldown.stl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]
2025-11-29 case update+tenting for mesh backplate
    [modubuCase_LHexMeshTent.stl, modubuCase_LMid.stl, modubuCase_LUp.stl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]
2025-12-07 add leafspring case
    [modubuCase_LMid.stl, modubuCase_LUp.stl, modubuCase_Ldown.stl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]
2025-12-07 add top mount case
    [modubuCase_LHexMeshTent.stl, modubuCase_LMid.stl, modubuCase_LUp.stl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]
2025-12-08 edit leafspring and remove topmount
    felt meaningless over test
    [modubuLeafspring_Ltop.stl, modubuLeafspring_Rtop.stl, modubuV2.3dm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]
2025-12-08 upload hexmesh backplate for leafspring
    [modubuLeafspring_Lback_HexMesh.stl, modubuLeafspring_Rback_HexMesh.stl]
2025-12-08 hotfix hole of leafspring hexmash
    [modubuLeafspring_Lback_HexMesh.stl, modubuLeafspring_Rback_HexMesh.stl]
2025-12-08 plate unit preservation edit
2025-12-10 upload viki case
    [modubuViki.3dm, modubuViki_LCase.stl, modubuViki_Lcase_HexMesh.stl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]
